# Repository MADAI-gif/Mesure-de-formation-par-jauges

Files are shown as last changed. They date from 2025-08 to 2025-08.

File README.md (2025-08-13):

# Mesure de Déformation par Jauges – Dispositif de Commande Haptique

## 📌 Description du projet
Ce projet a pour objectif de concevoir un **système de commande haptique** basé sur la mesure de déformation d’une lame métallique.  
Quatre jauges de déformation, montées en **pont de Wheatstone**, sont fixées sur la lame afin de mesurer les contraintes appliquées.  
Le signal issu du pont est amplifié par un **AD624** (carte de puissance) puis lu par une carte **Nucleo STM32** via l’entrée analogique PA0.  
Le traitement embarqué permet d’estimer la force appliquée et de piloter un **moteur pas à pas** en asservissement de position.

---

## 🎯 Objectifs
- Concevoir un système de mesure haptique fiable et précis.  
- Assurer la cohérence entre la force appliquée et le mouvement du moteur.  
- Calibrer le système pour obtenir une relation linéaire entre la tension mesurée et la déformation.  
- Valider le bon fonctionnement par comparaison entre résultats théoriques et expérimentaux.

---

## 🛠 Réalisations techniques
- **Capteur** : 4 jauges de déformation en pont de Wheatstone.  
- **Conditionnement du signal** : Amplificateur AD624.  
- **Acquisition** : Carte Nucleo STM32 (entrée analogique PA0).  
- **Actionneur** : Moteur pas à pas commandé en position.  
- **Interface Homme-Machine (IHM)** pour le suivi en temps réel.  
- **Carte de puissance** dédiée.  

---

## 📐 Méthodologie
1. **Montage mécanique** : fixation des jauges sur la lame métallique.  
2. **Montage électronique** : pont de Wheatstone → amplification analogique → acquisition STM32.  
3. **Calibration** : série de tests pour établir la relation tension–force–déformation.  
4. **Traitement logiciel** : calcul de la force appliquée et pilotage du moteur pas à pas.  
5. **Validation** : comparaison avec le modèle théorique.

---

## 📊 Résultats
- Relation linéaire observée entre tension mesurée et déformation/poids appliqué.  
- Écart faible entre théorie et expérience (dus aux pertes et imprécisions expérimentales).  
- Bonne réactivité et positionnement précis du moteur pas à pas.  
- Système fiable et stable lors des essais.

---

## 🔭 Perspectives
- Miniaturisation du dispositif.  
- Intégration d’un **retour de force** pour applications médicales ou aéronautiques.  
- Optimisation de l’IHM et du traitement embarqué.  

---

## 👥 Équipe
- Alexandre P.  
- Mathieu L.  
- Yvan M.  
- Madaï M.

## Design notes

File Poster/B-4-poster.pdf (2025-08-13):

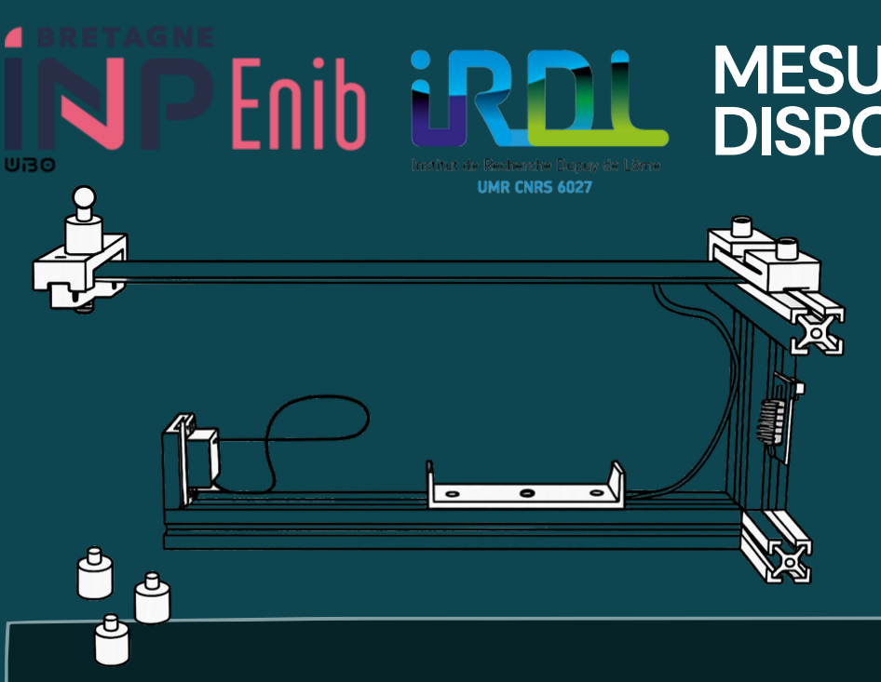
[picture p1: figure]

Ce projet nous a permis de concevoir un système de commande haptique constitué d’une lame métallique déformable. Quatre jauges de déformation, montées en pont de Wheatstone, sont fixées sur la lame. La tension issue du pont, amplifiée, est lue par la carte Nucleo STM32 via l’entrée analogique PA0. Cette tension varie en fonction de la force appliquée, ce qui permet de piloter un moteur pas à pas en ajustant son angle de rotation.

# MESURE DE DÉFORMATION PAR JAUGES DISPOSITIF DE COMMANDE HAPTIQUE

Alexandre P. Mathieu L. Yvan M. Madaï M.

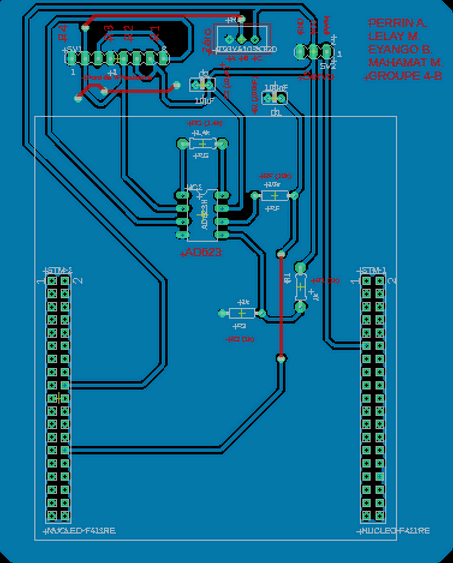
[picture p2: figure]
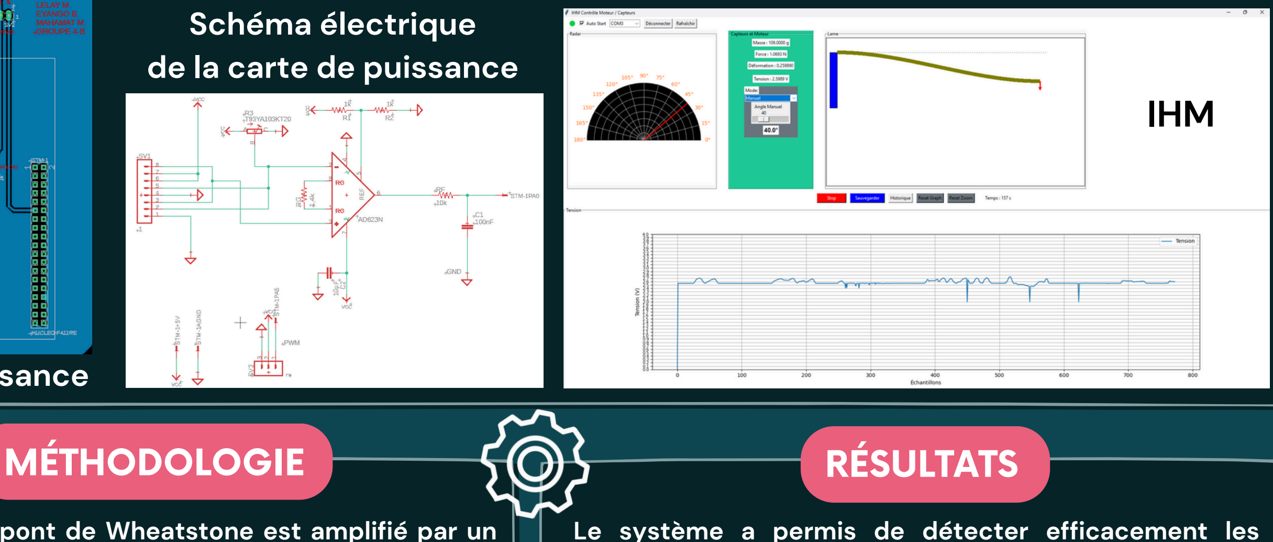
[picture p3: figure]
IHM; Schéma électrique de la carte de puissance; MÉTHODOLOGIE; RÉSULTATS

Notre étude théorique nous a permis de mettre en évidence une relation linéaire entre la tension mesurée (Vm) et la grandeur appliquée (longueur de déformation ou poids). On observe un léger écart entre les valeurs théoriques et expérimentales, dû à des pertes ou imprécisions expérimentales, mais la tendance reste conforme au modèle attendu, validant le bon fonctionnement du système de mesure.

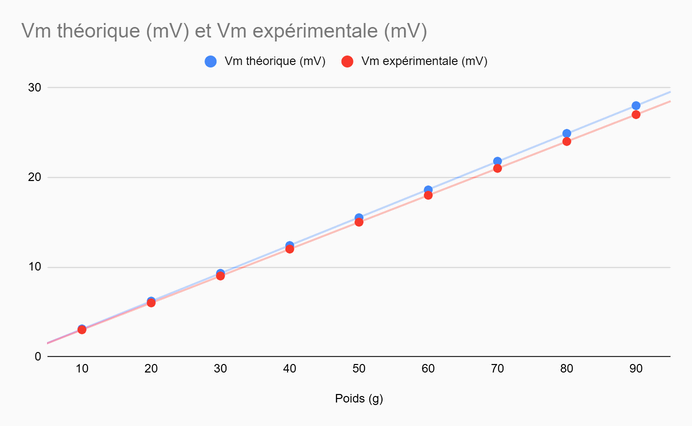
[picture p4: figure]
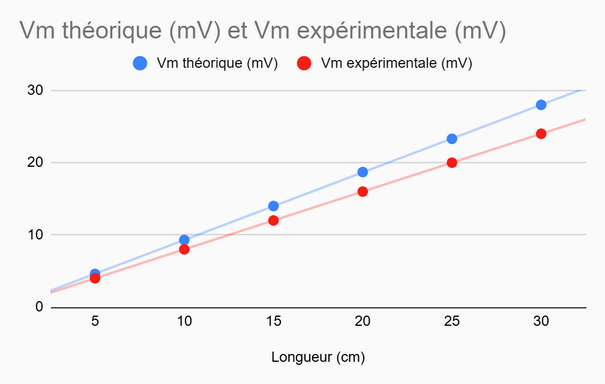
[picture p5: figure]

Nous envisageons d'étendre cette étude vers une miniaturisation du dispositif ou l'intégration d'un système de retour de force pour des applications en médecine et en aéronautique.

Ce projet a permis de concevoir un système de mesure haptique fiable, combinant jauges de déformation,
amplification | analogique | et
traitement embarqué. Les résultats montrent une bonne cohérence entre théorie et expérimentation

### Carte de puissance

Le signal issu du pont de Wheatstone est amplifié par un AD624 (carte de puissance), puis lu par la carte Nucleo STM32 via l’entrée analogique PA0. Ce signal est traité pour estimer la force appliquée, permettant de piloter un moteur pas à pas avec un asservissement en position. Le système a été calibré par une série de tests pour assurer la cohérence entre la force et le mouvement.

Le système a permis de détecter efficacement les variations de force appliquée sur la lame. La tension amplifiée variait de manière cohérente avec la déformation, et la conversion en angle de rotation du moteur pas à pas a montré une bonne réactivité. L’asservissement a permis un positionnement précis du moteur, avec une réponse stable lors des essais.

## OBJECTIFS

## RÉALISATIONS PHYSIQUES

### ÉTUDE THÉORIQUE & ANALYSE CRITIQUE DES RÉSULTATS

## CONCLUSION

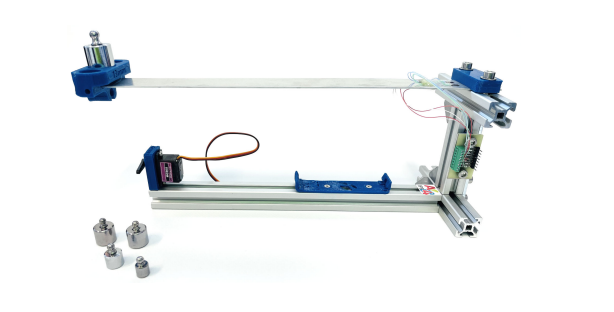
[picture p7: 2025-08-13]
IHM/ihm_background.PNG

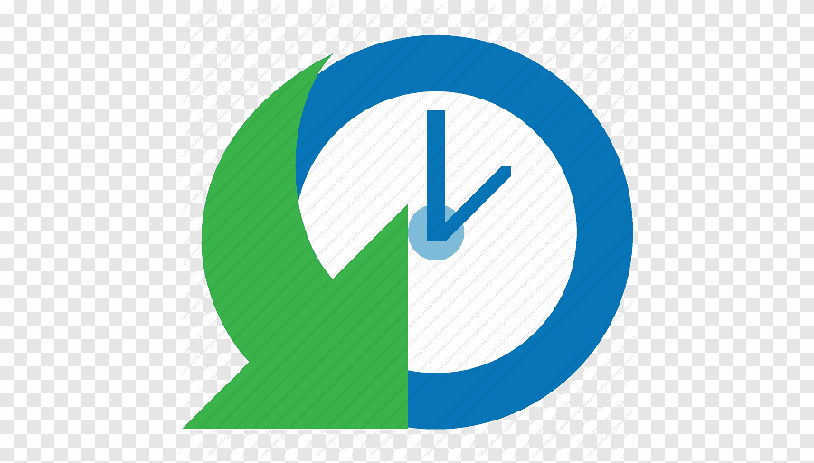
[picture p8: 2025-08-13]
IHM/historique.png

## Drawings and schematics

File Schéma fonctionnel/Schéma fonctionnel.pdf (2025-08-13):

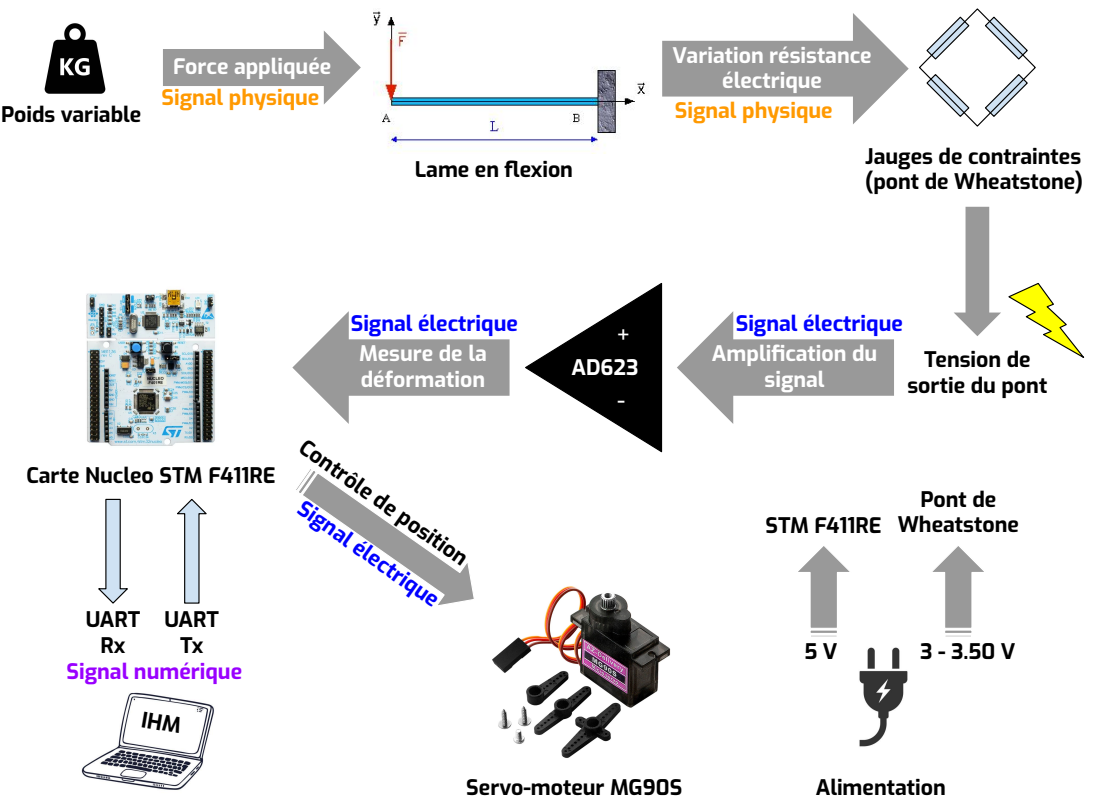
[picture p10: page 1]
Poids variable; Force appliquée; Variation résistance électrique; Amplification du signal; IHM; UART Tx; UART Rx; Alimentation; Servo-moteur MG90S; Signal physique; Signal électrique; Signal numérique

Jauges de contraintes
(pont de Wheatstone)

Lame en flexion

AD623 Mesure de la
déformation

Tension de
sortie du pont

Contrôle de position

Carte Nucleo STM F411RE

Wheatstone | Pont de

STM F411RE

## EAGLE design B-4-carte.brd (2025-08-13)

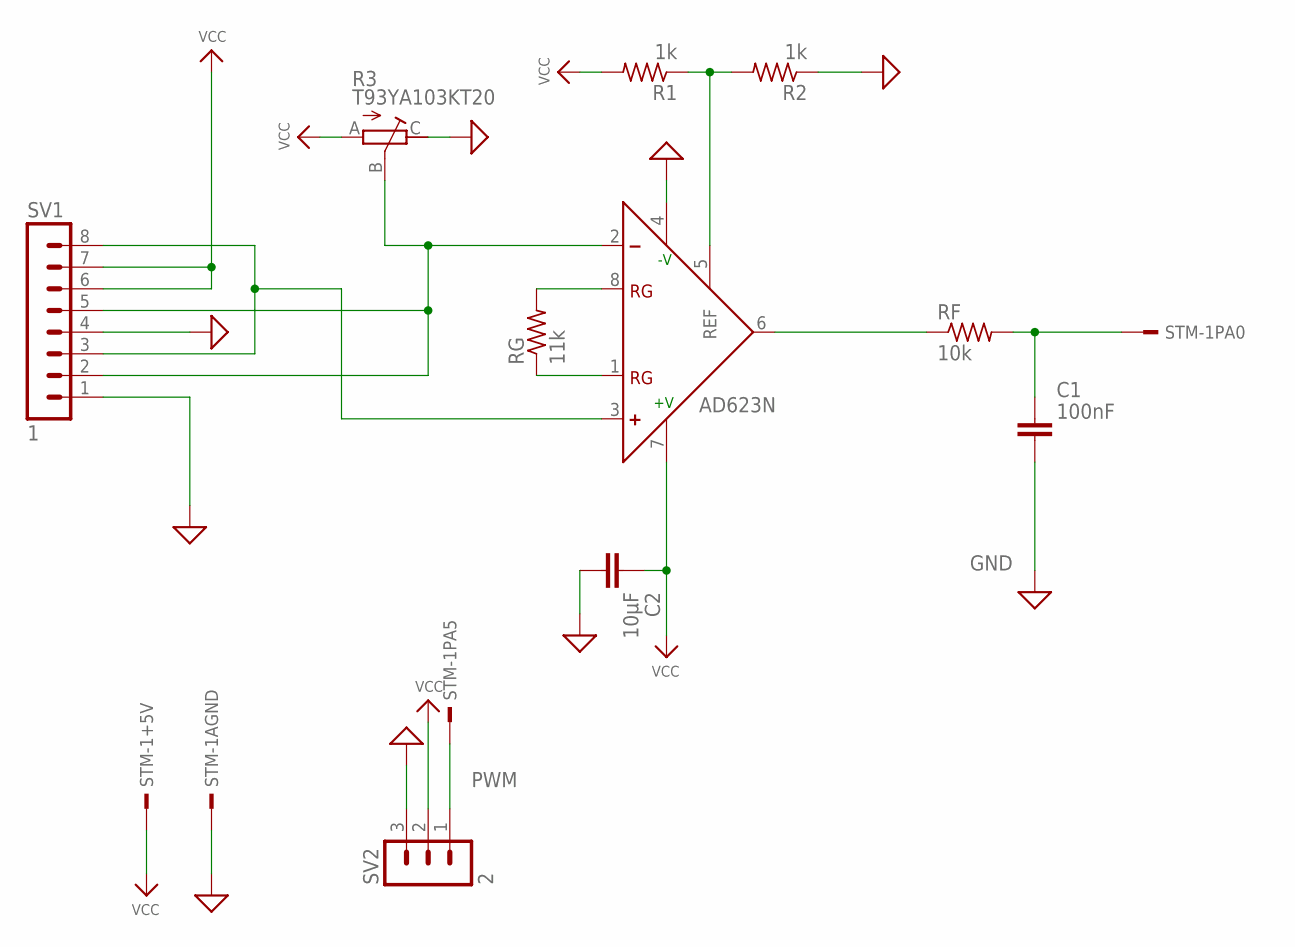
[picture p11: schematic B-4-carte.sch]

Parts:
C1: 100nF; C2.5-2
C2: 10µF; C2.5-2
IC1: AD623N; DIL08
R1, R2: 1k; 0204/7
R3: T93YA103KT20; TRIM_T93YA103KT20
RF: 10k; 0204/7
RG: 11k; 0204/7
STM-1: NUCLEO-F411RE; CONN_STM32_NUCLEO
SV1: 1; MA08-1
SV2: 2; MA03-1

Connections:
GND: C1.2, C2.2, IC1.4 (-V), R2.1, R3.C, STM-1.70, SV1.1, SV1.4, SV2.3
unnamed: IC1.3 (+), SV1.3, SV1.8
unnamed: C1.1, RF.2, STM-1.28
unnamed: IC1.2 (-), R3.B, SV1.2, SV1.5
unnamed: IC1.1 (RG), RG.1
unnamed: IC1.8 (RG), RG.2
unnamed: IC1.5 (REF), R1.1, R2.2
unnamed: IC1.6 (OUT), RF.1
PWM: STM-1.49, SV2.1
VCC: C2.1, IC1.7 (+V), R1.2, R3.A, STM-1.18, SV1.6, SV1.7, SV2.2

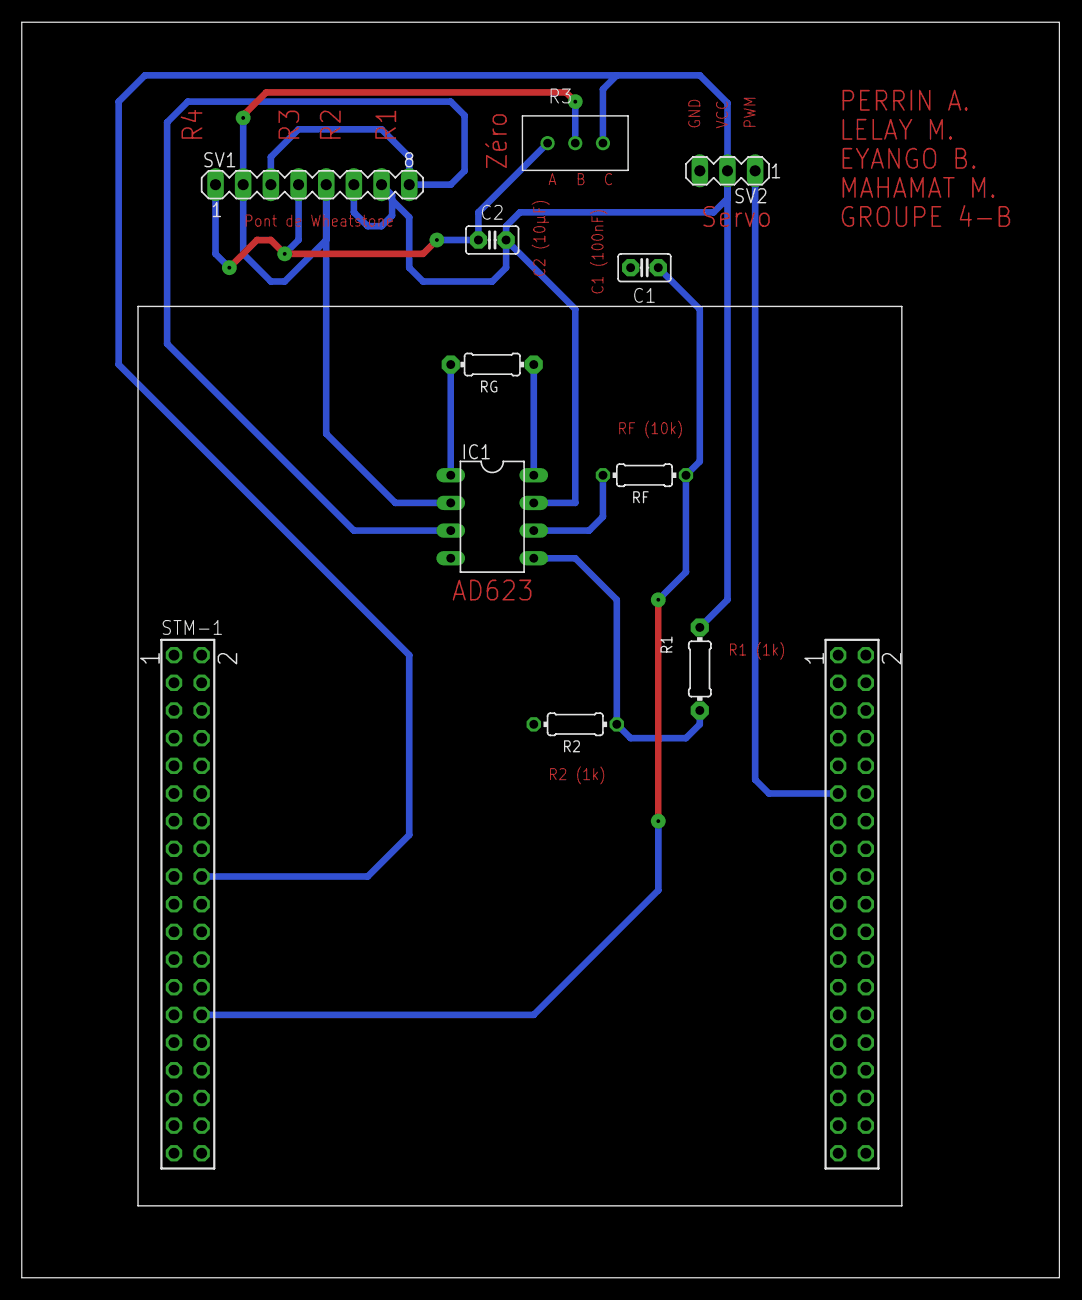
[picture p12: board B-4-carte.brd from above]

Board: 2 copper layers, 95.2 x 115.2 mm, 11 parts (0 on the bottom side), 10 nets.

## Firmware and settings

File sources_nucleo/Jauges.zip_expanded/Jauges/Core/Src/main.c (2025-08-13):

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
/* Includes ------------------------------------------------------------------*/
#include "main.h"
/* USER CODE BEGIN Includes */
#include <stdarg.h>
#include "util.h"    // Si tu déclares str2num, num2str, etc. ici

/* USER CODE END Includes */
/* USER CODE BEGIN PTD */
#define RING_BUF_SIZE	60
typedef volatile struct RingBuffer {
	char buf[RING_BUF_SIZE];
	int  i_push;		/* pointeur (index) d'écriture */
	int  i_pop;		/* pointeur (index) de lecture */
} RingBuffer;
static RingBuffer rx_buf = {
	.i_push=0,
	.i_pop=0
};
#define buffSize 		100
typedef volatile struct Buffer {
	int buff[buffSize][3];
	int index;
	int size;
} Buffer;
/* USER CODE END PTD */
/* USER CODE BEGIN PD */
#define ADC_SIZE 		1
#define txBufSendLEN 	1000 	// Taille buffer d'envoi des données
#define txBufReceiveLEN 10 		// Taille buffer de reception des données
#define ANGLE_MIN -90				// Angle minimal du servo moteur
#define ANGLE_MAX 180		// Angle maximal du servo moteur
#define L 0.3					// Longueur de la lame en mètres
#define B 0.03					// Largeur de la lame en mètres
#define H 0.003 				// Epaisseur de la lame en mètres
#define Eb 5					// Tension du pont de wheatstone
#define Gf 2					// Facteur de gauge (selon la documentation)
#define E 210000000000			// Module de Young de la lame en aluminium
#define g 9.81					// Constante de gravitée
#define correction 2.516			// Tension de correction
uint8_t VmIndex = 0; // Indice pour ajouter les nouvelles valeurs dans le tableau
uint16_t Vm;
/* USER CODE END PD */
ADC_HandleTypeDef hadc1;
DMA_HandleTypeDef hdma_adc1;
TIM_HandleTypeDef htim1;
TIM_HandleTypeDef htim2;
UART_HandleTypeDef huart2;
/* USER CODE BEGIN PV */
//Buffers
char txBufSend[txBufSendLEN];    				//envoi des données
char txBufReceive[txBufReceiveLEN];    			//reception des données
volatile uint32_t adcResultsDMA[ADC_SIZE];    	//récupération des valeur du DMA
int mode=2, servoMode=0, servoPos=0;
char commande[3][33];							//3 listes de 19 char
Buffer bufferCom = {    						//Buffer d'écriture permettant de ne pas envoyer des données en interruptions
		.index = 0,
		.size = buffSize
};
/* USER CODE END PV */
void SystemClock_Config(void);
static void MX_GPIO_Init(void);
static void MX_DMA_Init(void);
static void MX_ADC1_Init(void);
static void MX_USART2_UART_Init(void);
static void MX_TIM2_Init(void);
int put_char(char);
void term_printf_stlink(const char* fmt, ...);
/* USER CODE BEGIN PFP */
void HAL_UART_RxCpltCallback(UART_HandleTypeDef *huart);
float servo_writeAngle(int angle);
void computeData(const char* data);
int Angle(float masse);
float Masse(float v);
/* USER CODE END PFP */
#define per_deg 5.55  // pulse for 1° Rotation
uint16_t Vm;
char msg[555];
/**
 * @brief  The application entry point.
 * @retval int
 */
int main(void)
{
 /* MCU Configuration--------------------------------------------------------*/
 /* Reset of all peripherals, Initializes the Flash interface and the Systick. */
 HAL_Init();
 /* USER CODE BEGIN Init */
 HAL_MspInit();
 /* USER CODE END Init */
 /* Configure the system clock */
 SystemClock_Config();
 /* USER CODE BEGIN SysInit */
 /* USER COD 0E END SysInit */
 /* Initialize all configured peripherals */
 MX_GPIO_Init();
 MX_DMA_Init();
 MX_ADC1_Init();
 MX_USART2_UART_Init();
 MX_TIM2_Init();
 /* USER CODE BEGIN 2 */
 HAL_TIM_PWM_Start(&htim2, TIM_CHANNEL_1);
 HAL_TIM_Base_Start_IT(&htim2);
 /* USER CODE END 2 */
 /* Infinite loop */
 /* USER CODE BEGIN WHILE */
 float tension;
 float masse;
 float deformation;
 float force;
 float f;
 float h;
 while (1) {
     HAL_ADC_Start(&hadc1);
     //Attends la fin de la conversion pour Vm
     HAL_ADC_PollForConversion(&hadc1, 10);
     // Lit la valeur brute de l'ADC (12 bits)
     Vm = HAL_ADC_GetValue(&hadc1);
     // Conversion de la valeur brute d'ADC en tension
     tension = ((float)Vm / 4095.0) * 3.3 ;


     // Arrête l'ADC pour Vm
     HAL_ADC_Stop(&hadc1);
     // Calcul des différentes variables
     masse = Masse(tension); 						// Calculer la masse en g
     deformation = (tension) / (Gf * Eb); 			// Calculer la déformation
     force = masse*0.001*g;						//Calcul de la force*
     h = (tension-2)*100;
     // Affichage sur l'IHM
     sprintf(msg, "V: %f\r\n", tension);
     HAL_UART_Transmit(&huart2, (uint8_t*)msg, strlen(msg), HAL_MAX_DELAY);
     // Affichage et transmission de la masse équivalente
     sprintf(msg, "M: %f\r\n", masse);
     HAL_UART_Transmit(&huart2, (uint8_t*)msg, strlen(msg), HAL_MAX_DELAY);
    // sprintf(msg, "h: %f\r\n", h);
    // HAL_UART_Transmit(&huart2, (uint8_t*)msg, strlen(msg), HAL_MAX_DELAY);
     // Affichage et transmission de la déformation
     sprintf(msg, "D: %f\r\n", deformation);
     HAL_UART_Transmit(&huart2, (uint8_t*)msg, strlen(msg), HAL_MAX_DELAY);
	  // Affichage et transmission de l'effort sur l'IHM
     sprintf(msg,"F:%f\r\n",force);
     HAL_UART_Transmit(&huart2, (uint8_t*)msg, strlen(msg), HAL_MAX_DELAY);
     // Attente de 1 seconde
     HAL_Delay(45);
	  if (mode == 1) {  								// Mode manuel
	      float duty = servo_writeAngle(servoPos);  	// Calcul du duty cycle
	      htim2.Instance->CCR1 = duty;  				// Appliquer le duty cycle
	  }
	  else if (mode == 2) {  							// Mode automatique
		  int angleAuto = Angle(masse);	  				// Calculer l'angle du servomoteur en fonction de la masse
	      sprintf(msg,"A:%i\r\n",angleAuto);		// Affichage de l'angle sur l'IHM
	      HAL_UART_Transmit(&huart2, (uint8_t*)msg, strlen(msg), HAL_MAX_DELAY);
	      // Calculer le duty cycle en fonction de l'angle
	      float duty = servo_writeAngle(angleAuto);
	      htim2.Instance->CCR1 = duty;  // Appliquer le duty cycle
	      // Envoyer l'angle actuel via UART pour la synchronisation avec le frontend
	      term_printf_stlink("%d\r\n", angleAuto);
	  }
 }
}
float Masse(float v) {
    const float facteur_calibration = 7.0;
    static float tensions[5] = {0};  // Mémoire persistante
    static int index = 0;
    static int rempli = 0;

    float K, somme = 0.0;

    // Mise à 0 de la tension
    v -= correction;

    // Stocker la nouvelle valeur
    tensions[index] = v;
    index = (index + 1) % 5;

    // Savoir combien de valeurs valides on a
    int n = (rempli < 5) ? ++rempli : 5;

    // Calcul de la constante K
    K = (6 * Eb * Gf) / (E * B * H * H);

    // Calcul de la masse moyenne
    for (int i = 0; i < n; i++) {
        float masse_i = (tensions[i] / (K * L * g)) * facteur_calibration;
        somme += masse_i;
    }

    return somme / n;
}




int Angle(float masse) {
    float angle = masse;
    return (int)angle;
}
/*
float servo_writeAngle(int angle) {
   // Convertion de l'angle de la plage [0,180] vers [-90,90]
   angle = angle - 90;
   if (angle < ANGLE_MIN) {
   	angle = ANGLE_MIN;	// Si angle min atteind alors angle = angle min
   }
   if (angle > ANGLE_MAX) {
   	angle = ANGLE_MAX;	// Si angle max atteind alors angle = angle max
   }
   // Création de la commande du moteur via le duty
   //float duty = CCR_MIN + (((float)(angle - ANGLE_MIN) / (ANGLE_MAX - ANGLE_MIN)) * (CCR_MAX - CCR_MIN));
   float duty = 1.0 + (((angle + 90) / 109.0) * 1.0);
   float ticks = duty * 10.0;                         // conversion ms → ticks (100 µs par tick)
   return ticks;
   //float duty = angle;
   //return duty;
}
*/
float servo_writeAngle(int angle) {
    if (angle < -90) angle = -90;
    if (angle > 180) angle = 180;

    // Conversion angle [-90, 90] → duty [1.0 ms, 2.0 ms]
    float duty = 1.5 + ((float)angle / 180.0);  // linéaire autour de 1.5 ms
    float ticks = duty * 10.0; // conversion ms → ticks (100 µs par tick)
    return ticks;
}




void computeData(const char* data) {
   char buffer[50];  // Taille suffisante pour contenir la chaîne
   strncpy(buffer, data, sizeof(buffer));
   buffer[sizeof(buffer) - 1] = '\0';  // Sécurité : forcer la terminaison nulle
   char* token = strtok(buffer, ",");
   int i = 0;
   while (token && i < 2) {
       strcpy(commande[i], token);
       i++;
       token = strtok(NULL, ",");
   }
   mode = atoi(commande[0]);  // Premier paramètre : mode
   if (i > 1) {  // Deuxième paramètre : angle manuel
       int angle = atoi(commande[1]);
       if (angle >= ANGLE_MIN && angle <= ANGLE_MAX) {
           servoPos = angle;
       }
   }
}
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
/* USER CODE BEGIN 4 */
int put_char(char ch)
{
	HAL_UART_Transmit(&huart2, (uint8_t *)&ch, 1, 0xFFFF);
	return 0;
}
int putchar_stlink(char ch)
{
	HAL_UART_Transmit(&huart2, (uint8_t *)&ch, 1, 0xFFFF);
	return 0;
}
//=================================================================
//	Helper Functions and Buffer Management
//=================================================================
// Add data to the buffer
static void add_to_buffer(char data) {
   // Check if buffer is not full
   if ((rx_buf.i_push + 1) % RING_BUF_SIZE != rx_buf.i_pop) {
       // Add character to the buffer
       rx_buf.buf[rx_buf.i_push] = data;
       // Increment write index
       rx_buf.i_push = (rx_buf.i_push + 1) % RING_BUF_SIZE;
   }
}
// Clear the buffer
static void clear_buffer() {
   // Reset both read and write indices
   rx_buf.i_push = 0;
   rx_buf.i_pop = 0;
}
void put_string_stlink(char* s)
{
	while(*s != '\0')
	{
		putchar_stlink(*s);
		s++;
	}
}
void term_printf_stlink(const char* fmt, ...)
{
	va_list        ap;
	char          *p;
	char           ch;
	unsigned long  ul;
	unsigned long  size;
	unsigned int   sp;
	char           s[34];
	va_start(ap, fmt);
	while (*fmt != '\0') {
		if (*fmt =='%') {
			size=0; sp=1;
			if (*++fmt=='0') {fmt++; sp=0;}	// parse %04d --> sp=0
			ch=*fmt;
			if ((ch>'0') && (ch<='9')) {	// parse %4 d --> size=4
				char tmp[10];
				int i=0;
				while ((ch>='0') && (ch<='9')) {
					tmp[i++]=ch;
					ch=*++fmt;
				}
				tmp[i]='\0';
				size=str2num(tmp,10);
			}
			switch (ch) {
				case '%':
					 putchar_stlink('%');
					break;
				case 'c':
					ch = va_arg(ap, int);
					putchar_stlink(ch);
					break;
				case 's':
					p = va_arg(ap, char *);
					put_string_stlink(p);
					break;
				case 'd':
					ul = va_arg(ap, long);
					if ((long)ul < 0) {
						putchar_stlink('-');
						ul = -(long)ul;
						//size--;
					}
					num2str(s, ul, 10, size, sp);
					put_string_stlink(s);
					break;
				case 'u':
					ul = va_arg(ap, unsigned int);
					num2str(s, ul, 10, size, sp);
					put_string_stlink(s);
					break;
				case 'o':
					ul = va_arg(ap, unsigned int);
					num2str(s, ul, 8, size, sp);
					put_string_stlink(s);
					break;
				case 'p':
					putchar_stlink('0');
					putchar_stlink('x');
					ul = va_arg(ap, unsigned int);
					num2str(s, ul, 16, size, sp);
					put_string_stlink(s);
					break;
				case 'x':
					ul = va_arg(ap, unsigned int);
					num2str(s, ul, 16, size, sp);
					put_string_stlink(s);
					break;
				case 'f':
				    // Récupérer l'argument au format IEEE 754 (32 bits)
				    unsigned long ull = va_arg(ap, unsigned long);
				    // Extraire le signe, l'exposant, et la mantisse
				    int sign = (ull & 0x80000000) >> 31; // Bit de signe
				    int e = (ull & 0x7F800000) >> 23;    // Exposant (biaisé de 127)
				    int m = (ull & 0x007FFFFF);          // Mantisse
				    // Normaliser la mantisse
				    float mf = (float)m / 8388608.0; // Division par 2^23
				    mf += 1.0; // Ajout de 1 pour la normalisation
				    // Calcul de la valeur finale
				    e -= 127; // Suppression du biais de l'exposant
				    // Calcul de la puissance de 2 manuellement
				    float factor = 1.0;
				    if (e > 0) {
				        for (int i = 0; i < e; i++) {
				            factor *= 2.0; // Multiplication par 2 pour e > 0
				        }
				    } else if (e < 0) {
				        for (int i = 0; i < -e; i++) {
				            factor /= 2.0; // Division par 2 pour e < 0
				        }
				    }
				    // Calcul de la valeur réelle
				    float f = mf * factor; // Mantisse * 2^e
				    if (sign == 1) f = -f; // Ajout du signe
				    // Conversion en chaîne avec précision de 5 chiffres après la virgule
				    float2str((char *)s, f, 5);
				    // Afficher la chaîne résultante
				    put_string_stlink((char *)s);
				    break;
				default:
					putchar_stlink(*fmt);
			}
		} else putchar_stlink(*fmt);
		fmt++;
	}
	va_end(ap);
}
//fonction callback de réception de données sur le port série
void HAL_UART_RxCpltCallback(UART_HandleTypeDef *huart){
	HAL_UART_Receive_IT(&huart2, (uint8_t *)txBufReceive, 1);
	char car_received= (char)txBufReceive[0];
	//char 'e' mean end of commande
	if(car_received == 'e'){
		rx_buf.buf[rx_buf.i_push] = '\0';
		computeData((char*)rx_buf.buf);
		clear_buffer();
	}else{
		add_to_buffer(car_received);
	}
}
/* USER CODE END 4 */
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


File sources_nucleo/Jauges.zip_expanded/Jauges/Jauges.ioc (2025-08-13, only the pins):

Mcu.UserName=STM32F411RETx
PA0-WKUP.Signal=ADCx_IN0
PA2.Signal=USART2_TX
PA3.Signal=USART2_RX
PA5.Signal=S_TIM2_CH1_ETR

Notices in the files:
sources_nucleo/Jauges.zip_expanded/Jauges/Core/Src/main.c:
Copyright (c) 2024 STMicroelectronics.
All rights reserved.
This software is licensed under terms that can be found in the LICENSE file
